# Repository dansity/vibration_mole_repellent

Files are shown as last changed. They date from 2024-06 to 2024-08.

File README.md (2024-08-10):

# Vibration Mole Repellent device

## Why use a vibration mole repellent?
Vibration mole repellent devices are nothing new, they are on the market for over 30 years. They are also very simple, a vibration motor and some basic logic that turns them on.
Gardens with big dogs in them rarely have moles. The dogs create vibrations in the ground as they run and moles naturally avoid these gardens.
This device aims to mimic this effect.

## So why build your own?
Three reasons:
- You can tweak the vibration pattern so it will be like a dog running. As far as I know commercial ones don't have this feature or if they have its just a lame sequence.
- You can put very strong motors in it to affect bigger area - if you want.
- Infinetely repairable

> This device is going to be more expensive than a store bought mole repellent! It is only going to be somewhat economically viable if you can source 18650 batteries and make yourself a 3s battery pack.

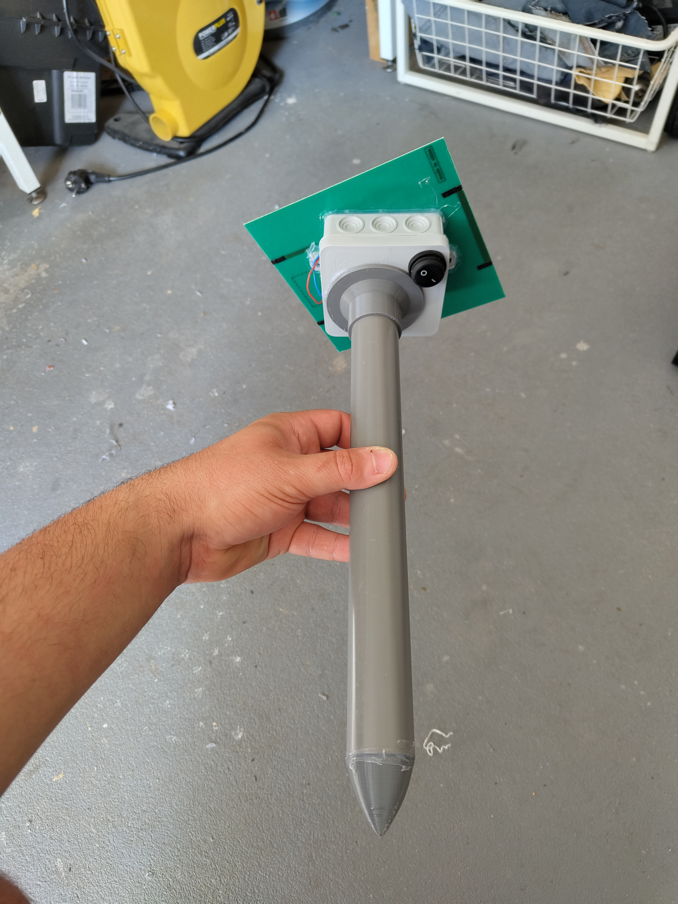
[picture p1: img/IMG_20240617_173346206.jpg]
Image of finished product


## Tools you need for the project
- Soldering iron
- PC with Arduino IDE v2 installed
- Glue gun
- Screw driver
- 3d printer optional
- Spot welder for batteries optional

## Shoppig list
(Aliexpress links)
- 12V vibration motor (the one with weight on both ends): https://www.aliexpress.com/item/1005005000354424.html
- 12V MPPT charging module: https://www.aliexpress.com/item/1005005997380493.html
- Solar Panel: https://www.aliexpress.com/item/1005007031699718.html
- Mosfet swith: https://www.aliexpress.com/item/1005006457613501.html
- Waterproof rocker switch: https://www.aliexpress.com/item/1005005695423032.html
- Cheapest ESP you can find ESP32-C3: https://www.aliexpress.com/item/1005006406538478.html
- Voltage sensor module: https://www.aliexpress.com/item/1005006385487339.html
- 3S BMS module: https://www.aliexpress.com/item/1005003986215534.html
- 3.3V step down module: https://www.aliexpress.com/item/1005007136976280.html

## Source locally
- 32mm PVC pipe, about 200mm length needed
- 0.14mm wires, black, red and one more color
- 75x75mm waterproof electronics box from electronics supply store

## Software
1. In Arduinio IDE v2 download Espressif ESP32 boards library (the one by Espressif not the Arduino)
2. Check and tweak settings if needed in the beginning of the code
3. Set USB CDC On BOOT - Disabled (else deep sleep pin state will not preserved). You can lower CPU clock if you want for extra power saving.
4. Flash firmware

## Hardware
Use attached wiring schematic
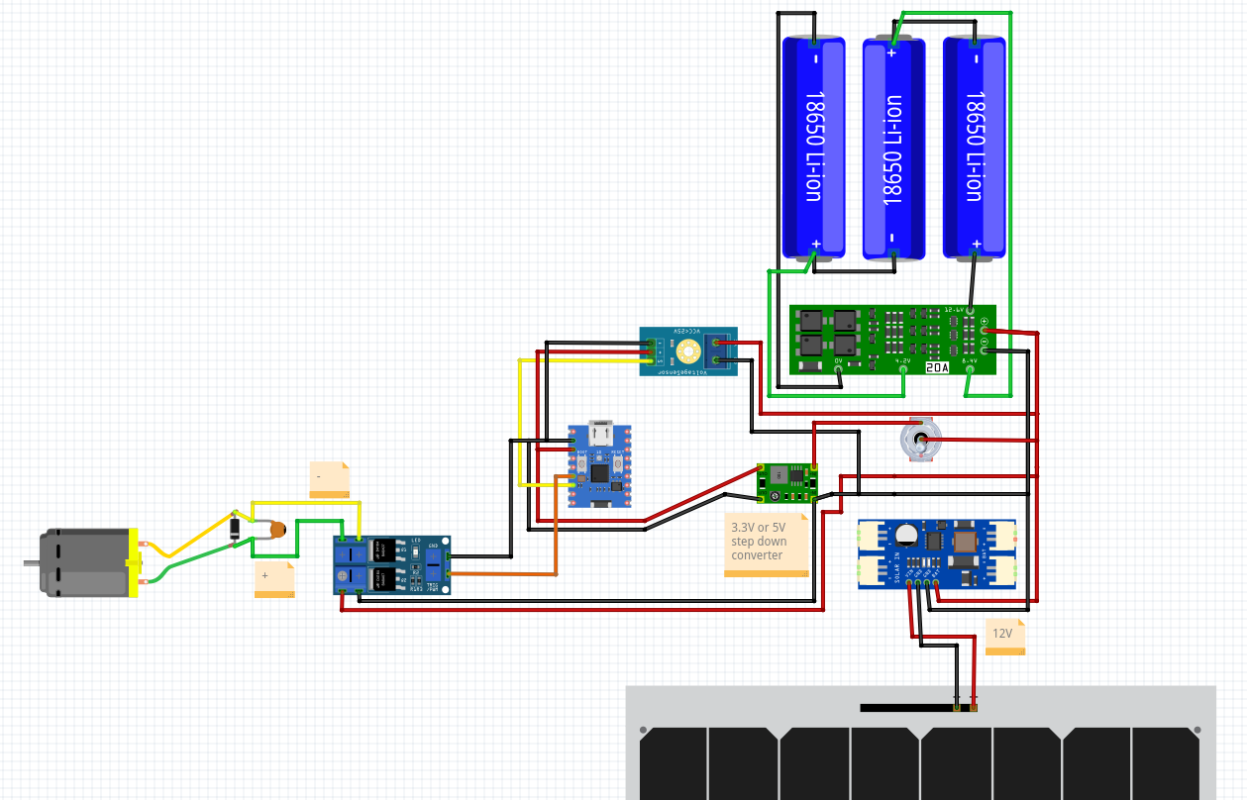
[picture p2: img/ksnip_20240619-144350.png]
Wiring schematic of mole repellent


Use Pin 0 for the voltage sensor and Pin 3 for the mosfet gate pin

Use a 3.3V step down module, don't trust the linear voltage regulators on cheap microcontrollers! They don't last long.

I rolled everything in kapton tape so they dont short and shoved it into the box.
Use irresponsible amount of hot glue to make everything stick together (optional)
Check images of my device in img directory.

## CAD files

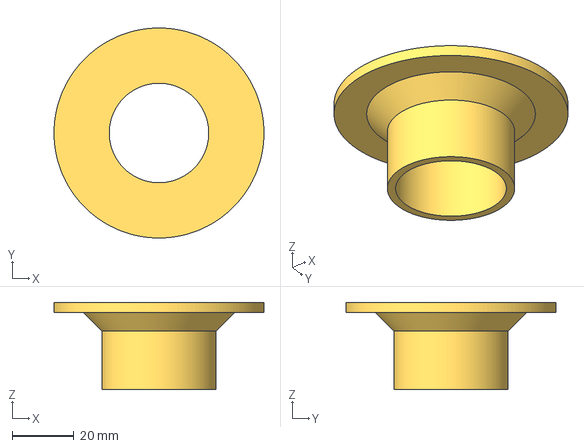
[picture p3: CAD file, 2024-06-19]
model/Adapter - Part 1.3mf
68.0 x 68.0 x 28.3 mm

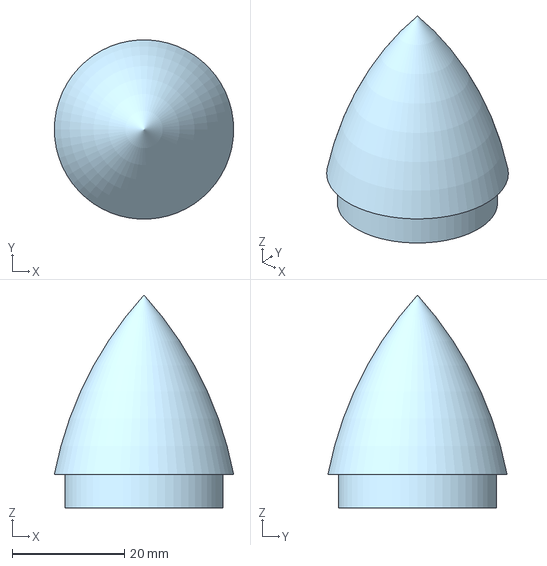
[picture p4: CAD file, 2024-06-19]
model/Cone - Part 1.3mf
32.0 x 32.0 x 38.0 mm

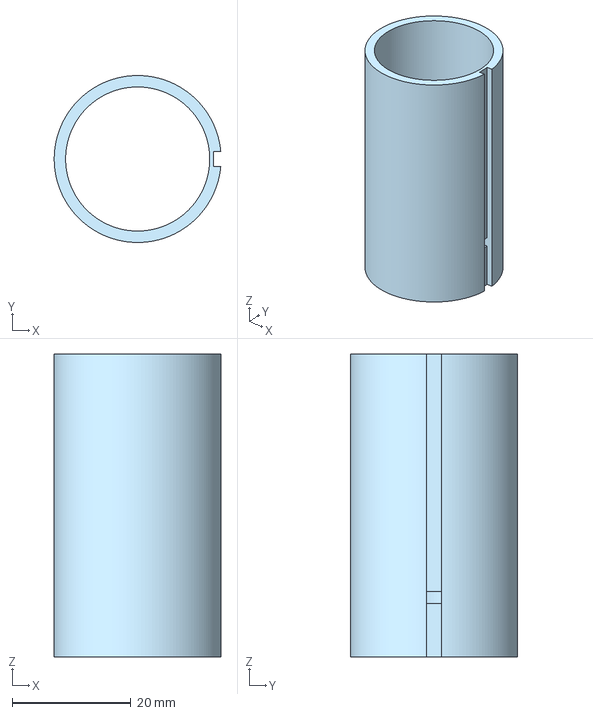
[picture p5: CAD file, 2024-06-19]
model/Motor Holder - Part 1.3mf
28.0 x 28.1 x 51.0 mm

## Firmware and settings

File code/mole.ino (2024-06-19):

// VIBRATION MOLE REPELLENT ...thingy
// Created by daninet - 2024
// More info and guide on the github page: https://github.com/daninet/vibration_mole_repellent


//                       ██████████████                                                
//                   ████░░░░░░░░░░░░░░██                                              
//                 ██░░░░░░░░░░░░░░░░░░░░████                                          
//             ████░░░░░░░░░░░░░░░░░░░░░░░░░░████████████████████                      
//       ██████░░░░░░░░░░░░████░░░░░░░░░░░░░░██░░░░░░░░░░░░░░░░░░██                    
//   ██████░░░░░░░░░░░░░░██    ██░░░░░░░░░░░░░░██░░░░░░░░░░░░░░░░░░██                  
// ██▓▓▓▓▓▓██░░░░░░░░░░░░██    ██░░░░░░░░░░░░░░░░██░░░░░░░░░░░░░░░░░░██                
// ██▓▓▓▓▓▓▓▓██░░░░░░░░░░░░████░░░░░░░░░░░░░░░░░░░░░░░░░░░░░░░░░░░░░░░░██              
//   ██▓▓▓▓██░░░░░░░░░░░░░░░░░░░░░░░░░░░░░░░░░░░░░░░░░░░░░░░░░░░░░░░░░░░░██            
//     ████░░░░░░░░░░░░░░░░░░░░░░░░░░░░░░░░░░░░░░░░░░░░░░░░░░░░░░░░░░░░░░██            
//       ██░░░░░░░░░░░░░░████████████░░░░░░░░░░░░░░░░░░░░░░░░░░░░░░░░░░░░██            
//         ████░░░░░░████░░░░░░░░░░░░██░░░░░░░░░░░░░░░░░░░░░░░░░░░░░░░░░░██████        
//       ██░░░░██████░░░░░░░░░░░░░░░░░░██░░░░░░░░░░░░░░░░░░░░░░░░░░░░░░░░██    ██      
//     ██░░░░██░░░░░░░░░░░░░░░░░░░░░░░░██░░░░░░░░████████████████░░░░░░░░████    ██    
//     ██████░░░░░░░░░░░░░░░░░░░░░░░░░░██░░░░░░██░░░░░░░░░░░░░░░░██░░░░░░██  ████      
//           ████  ██░░░░██░░░░░░░░░░░░██░░░░██░░░░░░░░░░░░░░░░░░░░██████              
//               ██░░░░██░░░░░░██░░░░██████████░░░░██░░░░░░██░░░░░░██                  
//             ██░░░░██░░░░░░██░░░░██        ██░░██░░░░░░██░░░░░░██                    
//           ██░░░░██░░░░████░░░░██            ██░░░░████░░░░░░██                      
//             ██████████  ██████                ████  ████████                        

//                      REPEL THE MOLES, DON'T KILL THEM                                                                                        

#include <driver/rtc_io.h>
#include <esp_sleep.h>
#include "driver/ledc.h"
#include "soc/rtc_cntl_reg.h"
#include "soc/rtc.h"

//==========================================
// SETTINGS

// SETUP YOUR PINS

// Define the GPIO pin for the mosfets switching the motor
const int mosfetPin = 3; 

// Define the Analog pin for the voltage sensor
const int voltagePin = 0; 

// Define the voltage threshold where the device will save a bit of power by vibrating less.
// For when you have long cloudy autumns and the solar panel is not making enough power.
const float voltageThreshold = 10.8;

// Short buzz length
const int shortBuzz = 1000; //ms

// Long buzz length
const int longBuzz = 3000; //ms

// Define the voltage divider resistor values (R1 and R2 in ohms)
// If you have used just two resistors you already know.
// If you purchased a sensor module chances are the below is correct
const float R1 = 30000.0;  // 30k ohms
const float R2 = 7500.0;  // 7.5k ohms

//ESPs and Arduinos measure voltage rather inaccurate, with up-to 10% error.
//Check the voltage in test mode and compensate here if it is off.
float actualVoltage1 = 10.0; 
float measuredVoltage1 = 10.86;  // Replace with your measured voltage
float actualVoltage2 = 12.6;
float measuredVoltage2 = 13.83;  // Replace with your measured voltage

// Boolean to enable/disable serial debug
bool enableDebug = true;

// Test mode - in testmode the ESP will not go into deep sleep so you can read the serial messages.
// In test mode the timeout is 1/10th of the real timeout, for example instead of 36sec it is 3.6sec
bool testMode = false;

// Motor max speed - Define the max speed of the motor on the range of 0-8191
// 8191 is 100% duty cycle for 13-bit resolution
// With some motors slower vibration is more effective as high speed makes it smoother

const int maxSpeed = 6000;

// END OF SETTINGS
//=========================================

// Motor PWM settings, ideally don't change it
#define LEDC_TIMER              LEDC_TIMER_0
#define LEDC_MODE               LEDC_LOW_SPEED_MODE
#define LEDC_OUTPUT_IO          mosfetPin // Define the output GPIO
#define LEDC_CHANNEL            LEDC_CHANNEL_0
#define LEDC_DUTY_RES           LEDC_TIMER_13_BIT // Set duty resolution to 13 bits
#define LEDC_DUTY               maxSpeed // Set duty cycle
#define LEDC_FREQUENCY          (4000) // Frequency in Hertz. Set frequency at 4 kHz

void setup() {
  if (enableDebug) {
    Serial.begin(9600);  // Initialize serial communication for debugging
  }
  
  // Disable deep sleep hold on the MOSFET pin if previously enabled
  gpio_hold_dis(static_cast<gpio_num_t>(mosfetPin));
  gpio_deep_sleep_hold_dis();

  // Initialize the MOSFET pin
  pinMode(mosfetPin, OUTPUT);
  digitalWrite(mosfetPin, LOW);  // Ensure the MOSFET is off initially

  // Initialize the voltage pin
  pinMode(voltagePin, INPUT);

  // Seed the random number generator with a unique value
  randomSeed(esp_random());
}

// LEDC config to create PWM
void ledc_init() {
    ledc_timer_config_t ledc_timer = {
        .speed_mode       = LEDC_MODE,
        .duty_resolution  = LEDC_DUTY_RES,
        .timer_num        = LEDC_TIMER,
        .freq_hz          = LEDC_FREQUENCY,  // Set output frequency at 4 kHz
        .clk_cfg          = LEDC_AUTO_CLK
    };
    ESP_ERROR_CHECK(ledc_timer_config(&ledc_timer));

    // Prepare and then apply the LEDC PWM channel configuration
    ledc_channel_config_t ledc_channel = {
        .gpio_num       = LEDC_OUTPUT_IO,
        .speed_mode     = LEDC_MODE,
        .channel        = LEDC_CHANNEL,
        .intr_type      = LEDC_INTR_DISABLE,
        .timer_sel      = LEDC_TIMER,
        .duty           = 0, // Set duty to 0%
        .hpoint         = 0
    };
    ESP_ERROR_CHECK(ledc_channel_config(&ledc_channel));
}

void setMosfet(bool state) {
  ESP_ERROR_CHECK(ledc_set_duty(LEDC_MODE, LEDC_CHANNEL, state ? LEDC_DUTY : 0));
  ESP_ERROR_CHECK(ledc_update_duty(LEDC_MODE, LEDC_CHANNEL));
}

//Setup voltage read compensation
float calculateCalibrationFactor(float actualVoltage1, float measuredVoltage1, float actualVoltage2, float measuredVoltage2) {
  float factor1 = actualVoltage1 / measuredVoltage1;
  float factor2 = actualVoltage2 / measuredVoltage2;
  float calibrationFactor = (factor1 + factor2) / 2;
  return calibrationFactor;
}

float readVoltage(float calibrationFactor) {
  int analogValue = analogRead(voltagePin);
  float voltage = analogValue * (3.3 / 4095.0);  // Convert analog reading to voltage
  float inputVoltage = voltage * ((R1 + R2) / R2);  // Calculate the input voltage
  float calibratedVoltage = inputVoltage * calibrationFactor;  // Apply calibration factor
  return calibratedVoltage;
}

// Generate a random time between 30 and 60 seconds
uint32_t sleepTime = 30 + esp_random() % 31;  // Random time between 30 and 60 seconds

//Main sleep fuction
void goToSleep() {
  if (enableDebug) {
    Serial.println("Going to sleep for: ");
    Serial.print(sleepTime);
    Serial.print(" seconds.");
    }

  // Ensure mosfet is off
  setMosfet(false);
  // Enable deep sleep hold on the MOSFET pin
  gpio_hold_en(static_cast<gpio_num_t>(mosfetPin));
  gpio_deep_sleep_hold_en();
  

  if (testMode == true) {
    //  In sleep mode we will just wait for a shorter timeout
    delay(sleepTime * 100);
  } else {
    // Convert sleep time to microseconds and set up deep sleep
    esp_sleep_enable_timer_wakeup(sleepTime * 1000000);
    esp_deep_sleep_start();
    }
}

//Main loop
void loop() {
  //Calibrate voltage read based on preset
  float calibrationFactor = calculateCalibrationFactor(actualVoltage1, measuredVoltage1, actualVoltage2, measuredVoltage2);
  float voltage = readVoltage(calibrationFactor);
    if (enableDebug) {
  Serial.println("Calibration Factor: " + String(calibrationFactor));
  Serial.println("Voltage: " + String(voltage));
    }

  //Initialize ledc for PWM
  ledc_init();

  //Patterns here, change to your liking
  if (voltage < voltageThreshold) {
    //LOW VOLTAGE PATTERN
      if (enableDebug) {
        Serial.println("Voltage low - Short buzz");
      }
    for (int i = 0; i < 2; i++) {
      setMosfet(true);
      delay(shortBuzz);
      setMosfet(false);
      delay(shortBuzz);
    }
  } else {
    // NORMAL VOLTAGE PATTERN
      if (enableDebug) {
        Serial.println("Voltage OK - Normal buzz sequence.");
      }
    for (int i = 0; i < 3; i++) {
      setMosfet(true);
      delay(shortBuzz);
      setMosfet(false);
      delay(shortBuzz);
    }

    setMosfet(true);
    delay(longBuzz);
    setMosfet(false);
  }
  // Initiate deep sleep
  goToSleep();
}
